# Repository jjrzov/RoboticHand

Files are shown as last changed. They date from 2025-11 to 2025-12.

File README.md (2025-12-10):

# ME 507 - Teleoperated Robot Hand
By: Sydney Alexander & Jorge Ramirez

This repository holds all the work done for our Fall 2025 ME 507 mechatronics 
class, Mechanical Control System Design. We chose to do a teleoperated
robot hand for our final project. The robot hand is controlled by a glove
that can be worn by the user. The user has control over each finger and a
palm bending motion on the robot hand.

The repository is split into 3 parts: 
* Mechanical Design Files (<https://github.com/jjrzov/RoboticHand/tree/main/CAD>)
* PCB Files
* Software Files    (<https://github.com/jjrzov/RoboticHand/tree/main/Code>)

More information can be found in the report:
<https://docs.google.com/document/d/1OJhpxcHGqPs-KphNlcnnhu6IluXgC120gNegF1xwxDM/edit?usp=sharing>

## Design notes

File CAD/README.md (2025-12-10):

This folder contains all of the CAD files necessary to construct the robotic hand.

Hand Assembly.SLDASM: Solidworks assembly containing the PCB, spacer, palm, mount, thumb, and one finger

Mount.SLDPRT: A Solidworks model of a mount for the hand to sit on

PCB Spacer.SLDPRT: A Solidworks model of a spacer to go between the palm and the PCB. Assembly contains 3

Palm.DXF: A DXF file of the palm that was used to design the PCB

Palm.SLDPRT: A Solidworks model of the palm, finger, and thumb

Passive Joint.SLDPRT: A Solidworks model of an attachment for the thumb joint (in Palm.SLDPRT)

RobotHandFINAL.step: A STEP file of the final PCB

Spool.SLDPRT: A Solidworks model of the spool. Assembly contains 5

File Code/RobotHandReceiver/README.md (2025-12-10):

# Robot Hand Receiver

This folder contians the platform.io project for the receiver in the project.
The receiver is tasked with receiving flex readings from the transmitter and
moving the motors to bend the finger(s) to match the user's movements.



There are 2 tasks for this project, the Receiver Task and the Controller Task. The Receiver Task is blocking waiting for the ESP-NOW callback to run meaning that data from the transmitter has arrived. The callback is made to be extermely fast and quick to ensure safe non critical behavior:

```
/**
 * @brief ESP-NOW receive callback.
 *
 * Copies the received packet into a FreeRTOS queue for processing
 * by ::ReceiverTask.
 *
 * @param mac          MAC address of sender.
 * @param incomingData Pointer to received data buffer.
 * @param len          Length of received data in bytes.
*/
void OnDataRecv(const uint8_t * mac, const uint8_t *incomingData, int len) {  
  Hand_Data data;
  memcpy(&data, incomingData, sizeof(data));
  xQueueSend(packet_queue, &data, 0);

  return;
}
```

Since the transmitter is unicasting specifically to the MAC address of the receiver ESP32, we do not need to worry about setting up the MAC address like we did in the receiver.

Once having received data the Receiver Task converts the raw flex readings into potentiometer-space targets:

```
float ratio = (flex_value - F_MIN) / (F_MAX - F_MIN);
float enc   = E_MIN + ratio * (E_MAX - E_MIN);
```
Each target is then sent to it's dedicated finger queue. Similar to the Transmitter Task, a Hand class is used to house all the queues.

The Controller Task implements a 2 state FSM:



Though before entering a state, the Controller reads from the encoders on each loop. There are rotary potentiometers attached to each motor that serve as encoder values. To read the current position of each motor, the potentiometers are connected to an 8 channel external ADC chip that communicates over I2C. We use the official Adafruit library for interfacing with this chip:

```
/**
 * @brief External ADC instance for rotary encoder (potentiometer) readings.
*/
Adafruit_ADS7830 ad7830;
```

In the Homing state, each funger motor is driver towards a known home position

```
Hand_Data home = {20, 20, 20, 20, 20, 20};
```

Once all the fingers are homed the system transition to Position Control state. During position control, the task performs non blocking reads of the latest target value from the finger queues:

```
if (xQueueReceive(glove.thumb_queue, &val, 0) == pdTRUE)
  targets.thumb_data = val;

```

For both Homing and Position Control, motor movement is calculated through a PID. Each finger/joint has its own PID that takes in the current potentiometer value and the target potentiometer value. There are 2 separate functions for running the PID in the Homing state versus the Position Control state. The Homing state only utilizes a P controller while the Position Control has a PID controller. 

```
void PositionControlFinger(uint32_t enc, uint32_t target, PID_t *pid, int pwm_channel, int phase_pin, float dt);

bool HomeFinger(uint32_t enc, uint32_t home_target, int pwm_channel, int phase_pin);
```

This distinction was made because when homing we only want to be around a certain threshold of potentiometer values to be home but we want more precise control when trying to match the user's motion.

The magnitude of the PID and P controller becomes the speed of the motor.

PID Controller:

```
float error = (float)target - (float)enc;
float u = PID_Step(pid, error, dt);  // signed

SetPhase(u, phase_pin); // Find direction to move in

float mag = fabsf(u);
int pwm = (int)mag;
```

P Controller:
```
float u = HOMING_KP * (float)err;
SetPhase(u, phase_pin);

float mag_u = fabsf(u);
int pwm = (int)mag_u; 
```

while the direction comes from the sign of the output.

```
/**
 * @brief Set motor direction based on signed control effort.
 *
 * Uses the sign of the control signal to determine the motor
 * rotation direction via the phase pin.
 *
 * @param u               Signed control output.
 * @param motor_phase_pin GPIO pin controlling motor direction.
 */
void SetPhase(float u, uint32_t motor_phase_pin) {
  digitalWrite(motor_phase_pin,(u >= 0.0f) ? HIGH : LOW);
}
```

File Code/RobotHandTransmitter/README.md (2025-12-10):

# Robot Hand Transmitter

This folder holds the platform.io project for the transmitter. The main task of
this project is to read the bend of the glove and transmit the data to the 
receiver.

In order to mimic the user's hand motions while wearing the glove, we used flex
sensors that act like potentiometers. Depending on how much the user is bending
the flex sensor, the resistance will increase or decrease. By creating a simple
voltage divider circuit with the flex sensor and a 100 ohm resistor, we can read
how the voltage is changing through ADC channels on our ESP-32.



Delving into the software, we can see the basic task architecure above. There are only 2 tasks for this project with the read sensors task running every 10ms and then sending that data over to the transmit task to then be sent to the receiver. 

Each finger has its own queue when communicating between tasks, but to make the code simpler a Hand class was created. This Hand class holds all the queues and is used as a way to access each queue from the tasks.

In the read sensors task, the voltage is read from each flex sensor and published to a queue. The transmit task is constantly reading from each queue until it is empty. An average is then taken while making sure to avoid dividng by zero. 

```
  // Read from queue until empty and take average
  while(xQueueReceive(queue, &reading, 0) == pdTRUE) {
    sum += reading;
    count++;
  }

  if (count > 0) {
    return (sum / count);
  } else {
    return 0; // Don't want to divide by zero if nothing in queue
  }
```

Setup for ESP-NOW is all done in the setup function before the scheduler begins. To avoid broadcasting to any ESP-32s nearby, we broadcast specifically to the MAC address of the device we want

```
  // Register peer
  memcpy(peerInfo.peer_addr, BROADCAST_ADDRESS, 6);
  peerInfo.channel = 0;  
  peerInfo.encrypt = false;

  // Add peer        
  if (esp_now_add_peer(&peerInfo) != ESP_OK){
    Serial.println("Failed to add peer");
    return false;
  }
```

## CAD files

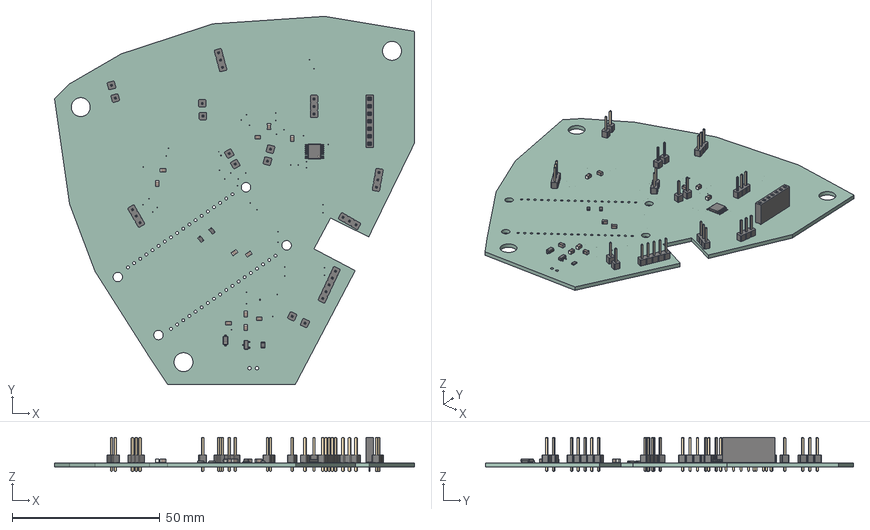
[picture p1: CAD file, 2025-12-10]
CAD/RobotHandFINAL.step
121.9 x 124.7 x 11.6 mm
D_SOD-123
R_0805_2012Metric x 3
PinHeader_1x01_P2.54mm_Vertical x 10
C_0805_2012Metric x 11
PinHeader_1x03_P2.54mm_Vertical x 5
PinSocket_1x07_P2.54mm_Vertical
PinHeader_1x05_P2.54mm_Vertical
TSSOP-16_4.4x5mm_P0.65mm
SOT-23-3
RobotHandFINAL_PCB

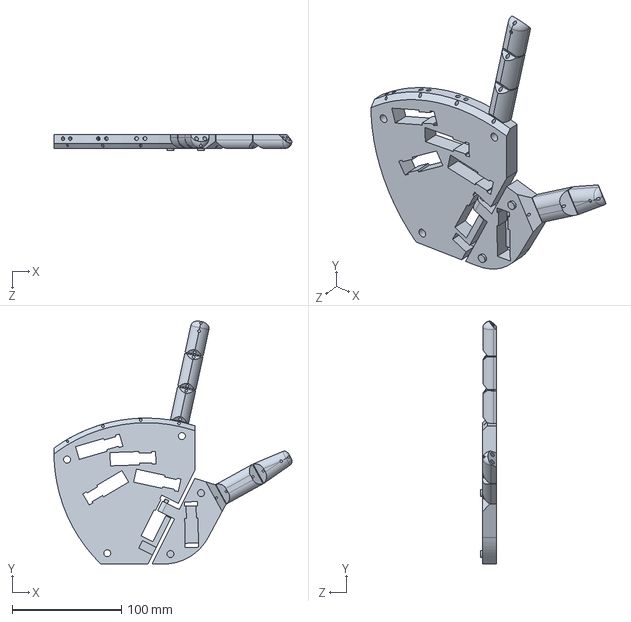
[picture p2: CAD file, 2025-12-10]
CAD/Palm.SLDPRT
217.5 x 222.1 x 14.7 mm

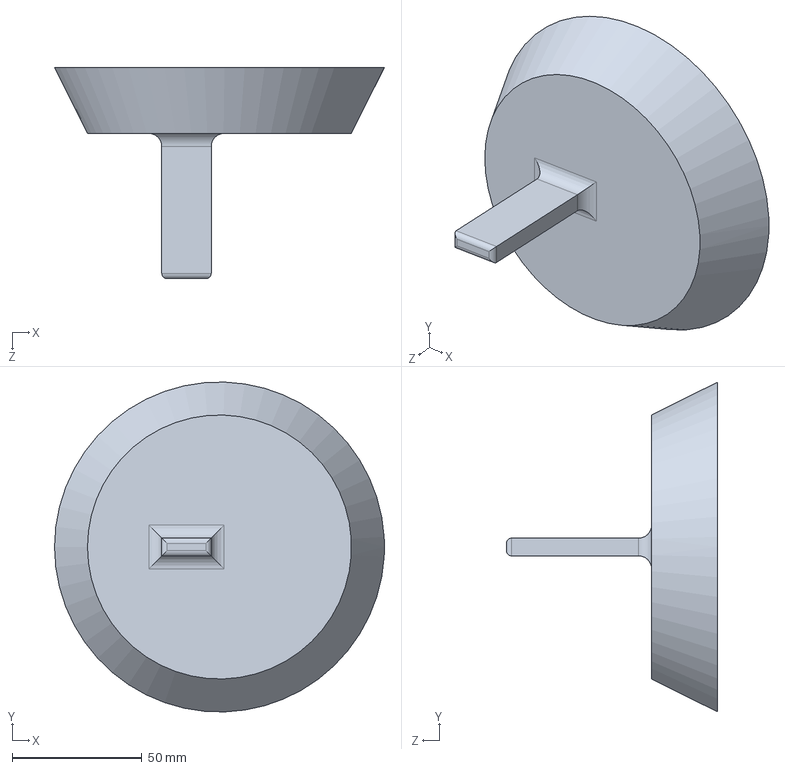
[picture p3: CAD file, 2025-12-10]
CAD/Mount.SLDPRT
127.0 x 126.9 x 81.3 mm

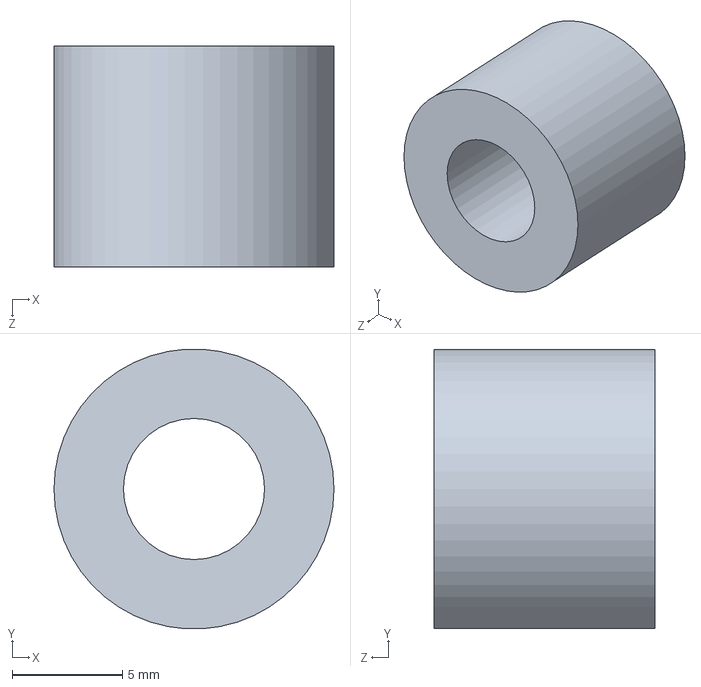
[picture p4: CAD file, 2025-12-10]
CAD/PCB Spacer.SLDPRT
12.7 x 12.7 x 10.0 mm

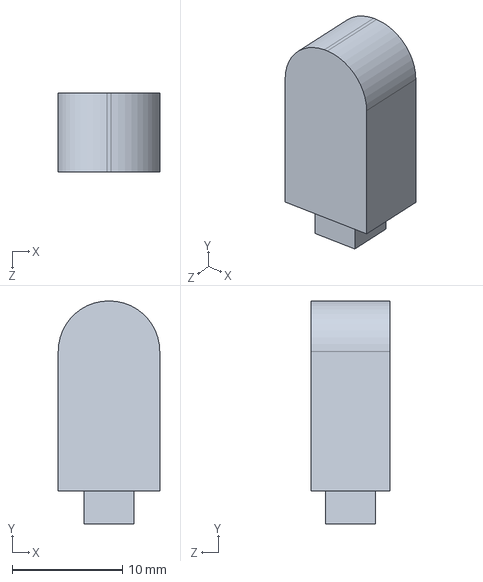
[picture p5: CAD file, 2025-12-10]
CAD/Passive Joint.SLDPRT
9.23 x 20.3 x 7.14 mm

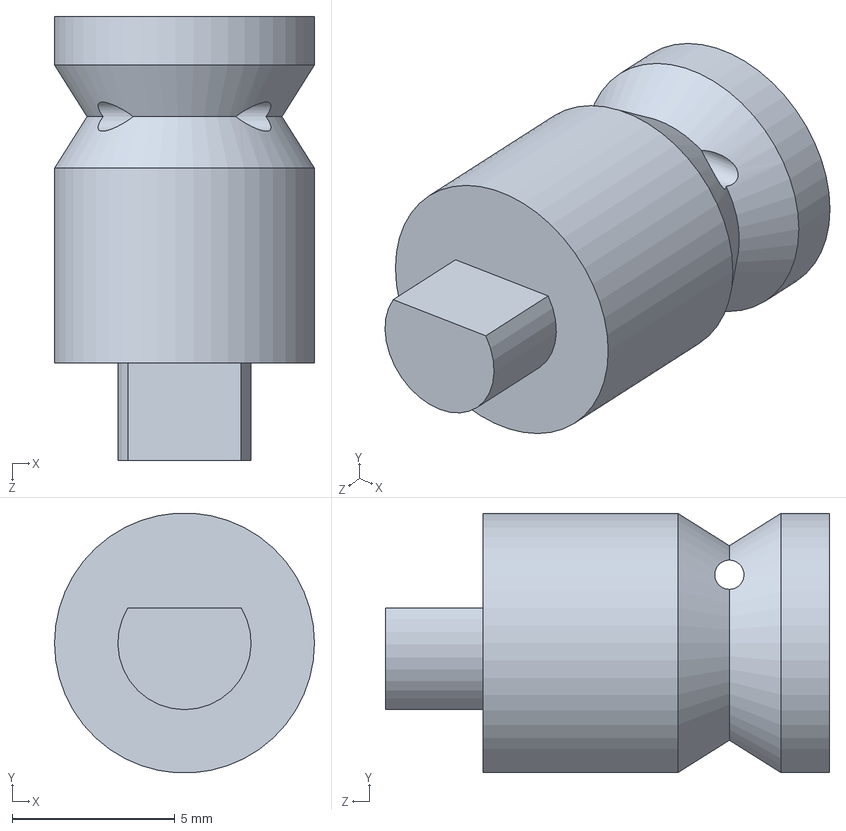
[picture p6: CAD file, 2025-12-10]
CAD/Spool.SLDPRT
8.00 x 7.98 x 13.7 mm

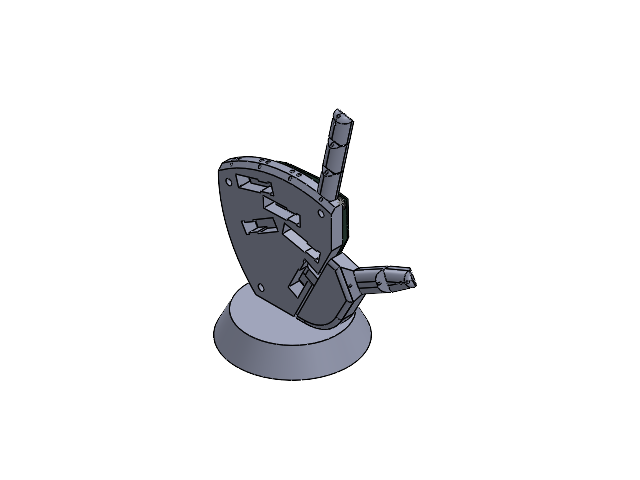
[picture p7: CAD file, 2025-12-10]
CAD/Hand Assembly.SLDASM
Palm
D_SOD-123.step
R_0805_2012Metric.step x 3
PinHeader_1x01_P2.54mm_Vertical.step x 10
C_0805_2012Metric.step x 11
PinHeader_1x03_P2.54mm_Vertical.step x 5
PinSocket_1x07_P2.54mm_Vertical.step
PinHeader_1x05_P2.54mm_Vertical.step
TSSOP-16_4.4x5mm_P0.65mm.step
SOT-23-3.step
RobotHandFINAL_PCB.step
PCB Spacer
Mount

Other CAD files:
CAD/Palm.DXF

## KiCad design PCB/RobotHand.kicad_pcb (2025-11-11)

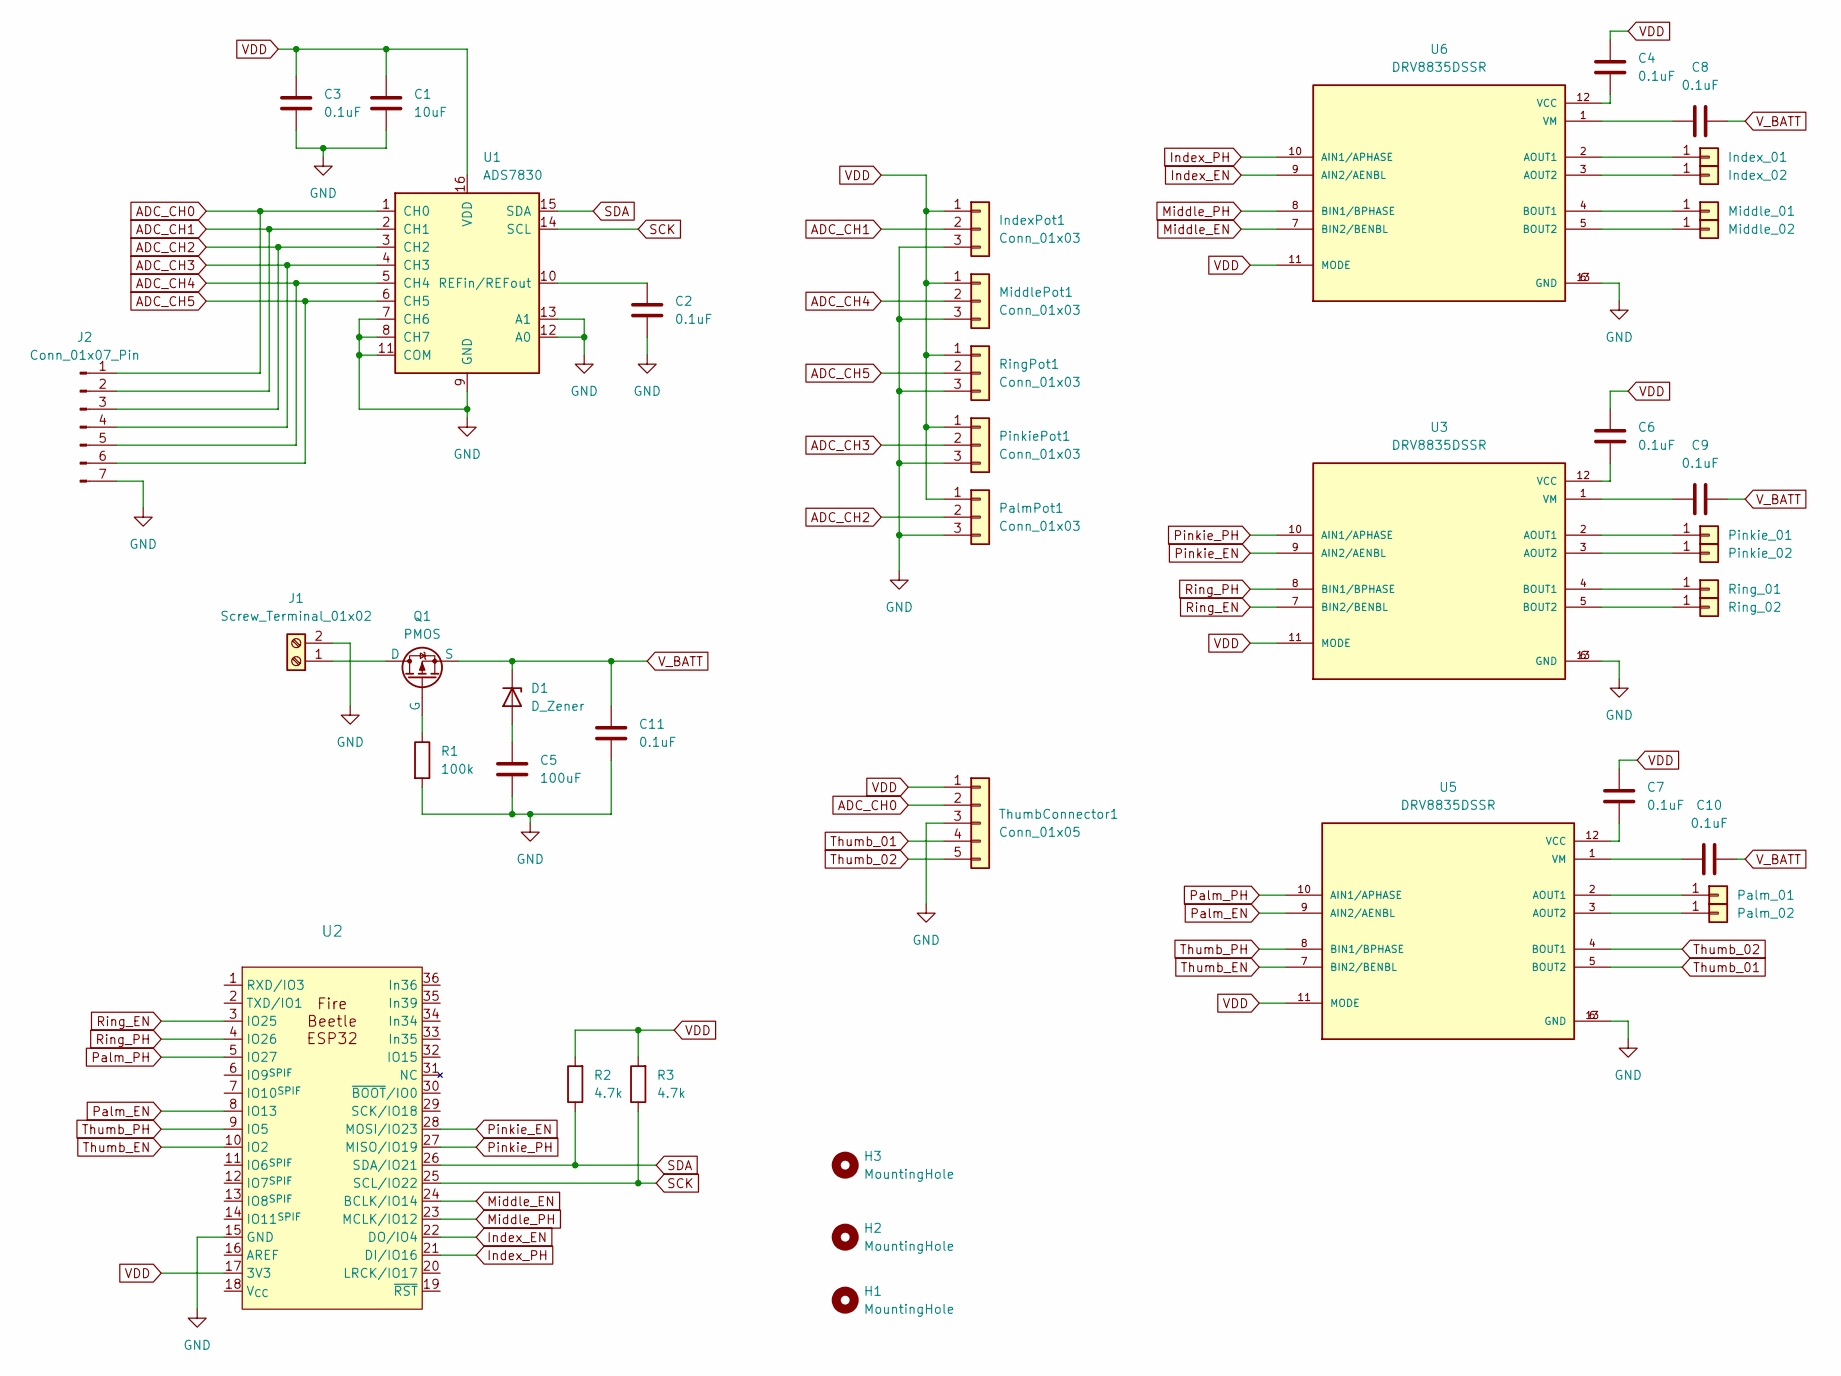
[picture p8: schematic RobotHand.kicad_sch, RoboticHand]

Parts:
C1: 10uF; C_0805_2012Metric_Pad1.18x1.45mm_HandSolder
C2, C3, C4, C6, C7, C8, C9, C10, C11: 0.1uF; C_0805_2012Metric_Pad1.18x1.45mm_HandSolder
C5: 100uF; C_0805_2012Metric_Pad1.18x1.45mm_HandSolder
D1: D_Zener; D_SOD-123
H1, H2, H3: MountingHole; MountingHole_6.4mm_M6
IndexPot1: Conn_01x03; PinHeader_1x03_P2.54mm_Vertical
Index_01, Index_02: Conn_01x01; PinHeader_1x01_P2.54mm_Vertical
J1: Screw_Terminal_01x02; TerminalBlock_Xinya_XY308-2.54-2P_1x02_P2.54mm_Horizontal
J2: Conn_01x07_Pin; PinSocket_1x07_P2.54mm_Vertical
MiddlePot1: Conn_01x03; PinHeader_1x03_P2.54mm_Vertical
Middle_01, Middle_02: Conn_01x01; PinHeader_1x01_P2.54mm_Vertical
PalmPot1: Conn_01x03; PinHeader_1x03_P2.54mm_Vertical
Palm_01, Palm_02: Conn_01x01; PinHeader_1x01_P2.54mm_Vertical
PinkiePot1: Conn_01x03; PinHeader_1x03_P2.54mm_Vertical
Pinkie_01, Pinkie_02: Conn_01x01; PinHeader_1x01_P2.54mm_Vertical
Q1: PMOS; SOT-23-3
R1: 100k; R_0805_2012Metric
R2, R3: 4.7k; R_0805_2012Metric
RingPot1: Conn_01x03; PinHeader_1x03_P2.54mm_Vertical
Ring_01, Ring_02: Conn_01x01; PinHeader_1x01_P2.54mm_Vertical
ThumbConnector1: Conn_01x05; PinHeader_1x05_P2.54mm_Vertical
U1: ADS7830; TSSOP-16_4.4x5mm_P0.65mm
U2: FireBeetle-ESP32
U3, U5, U6: DRV8835DSSR; WSON-12-1EP_3x2mm_P0.5mm_EP1x2.65; PARTREV H

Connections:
ADC_CH0: J2.1, ThumbConnector1.2, U1.1 (CH0)
ADC_CH1: IndexPot1.2, J2.2, U1.2 (CH1)
ADC_CH2: J2.3, PalmPot1.2, U1.3 (CH2)
ADC_CH3: J2.4, PinkiePot1.2, U1.4 (CH3)
ADC_CH4: J2.5, MiddlePot1.2, U1.5 (CH4)
ADC_CH5: J2.6, RingPot1.2, U1.6 (CH5)
GND: C1.1, C2.2, C3.2, C5.2, C11.2, IndexPot1.3, J1.2, J2.7, MiddlePot1.3, PalmPot1.3, PinkiePot1.3, R1.2, RingPot1.3, ThumbConnector1.3, U1.7 (CH6), U1.8 (CH7), U1.9 (GND), U1.11 (COM), U1.12 (A0), U1.13 (A1), U2.15 (GND), U3.6 (GND), U3.13 (GND), U5.6 (GND), U5.13 (GND), U6.6 (GND), U6.13 (GND)
Index_EN: U2.22 (DO/IO4), U6.9 (AIN2/AENBL)
Index_PH: U2.21 (DI/IO16), U6.10 (AIN1/APHASE)
Middle_EN: U2.24 (BCLK/IO14), U6.7 (BIN2/BENBL)
Middle_PH: U2.23 (MCLK/IO12), U6.8 (BIN1/BPHASE)
unnamed: C5.1, D1.2 (A)
unnamed: Index_01.1, U6.2 (AOUT1)
unnamed: Index_02.1, U6.3 (AOUT2)
unnamed: J1.1, Q1.1 (D)
unnamed: Middle_01.1, U6.4 (BOUT1)
unnamed: Middle_02.1, U6.5 (BOUT2)
unnamed: Palm_01.1, U5.2 (AOUT1)
unnamed: Palm_02.1, U5.3 (AOUT2)
unnamed: Pinkie_01.1, U3.2 (AOUT1)
unnamed: Pinkie_02.1, U3.3 (AOUT2)
unnamed: Q1.2 (G), R1.1
unnamed: Ring_01.1, U3.4 (BOUT1)
unnamed: Ring_02.1, U3.5 (BOUT2)
unnamed: C2.1, U1.10 (REFin/REFout)
unnamed: C6.1, U3.12 (VCC)
unnamed: C9.1, U3.1 (VM)
unnamed: C7.1, U5.12 (VCC)
unnamed: C10.2, U5.1 (VM)
unnamed: C4.1, U6.12 (VCC)
unnamed: C8.1, U6.1 (VM)
Palm_EN: U2.8 (IO13), U5.9 (AIN2/AENBL)
Palm_PH: U2.5 (IO27), U5.10 (AIN1/APHASE)
Pinkie_EN: U2.28 (MOSI/IO23), U3.9 (AIN2/AENBL)
Pinkie_PH: U2.27 (MISO/IO19), U3.10 (AIN1/APHASE)
Ring_EN: U2.3 (IO25), U3.7 (BIN2/BENBL)
Ring_PH: U2.4 (IO26), U3.8 (BIN1/BPHASE)
SCK: R3.1, U1.14 (SCL), U2.25 (SCL/IO22)
SDA: R2.1, U1.15 (SDA), U2.26 (SDA/IO21)
Thumb_01: ThumbConnector1.4, U5.5 (BOUT2)
Thumb_02: ThumbConnector1.5, U5.4 (BOUT1)
Thumb_EN: U2.10 (IO2), U5.7 (BIN2/BENBL)
Thumb_PH: U2.9 (IO5), U5.8 (BIN1/BPHASE)
VDD: C1.2, C3.1, C4.2, C6.2, C7.2, IndexPot1.1, MiddlePot1.1, PalmPot1.1, PinkiePot1.1, R2.2, R3.2, RingPot1.1, ThumbConnector1.1, U1.16 (VDD), U2.17 (3V3), U3.11 (MODE), U5.11 (MODE), U6.11 (MODE)
V_BATT: C8.2, C9.2, C10.1, C11.1, D1.1 (K), Q1.3 (S)

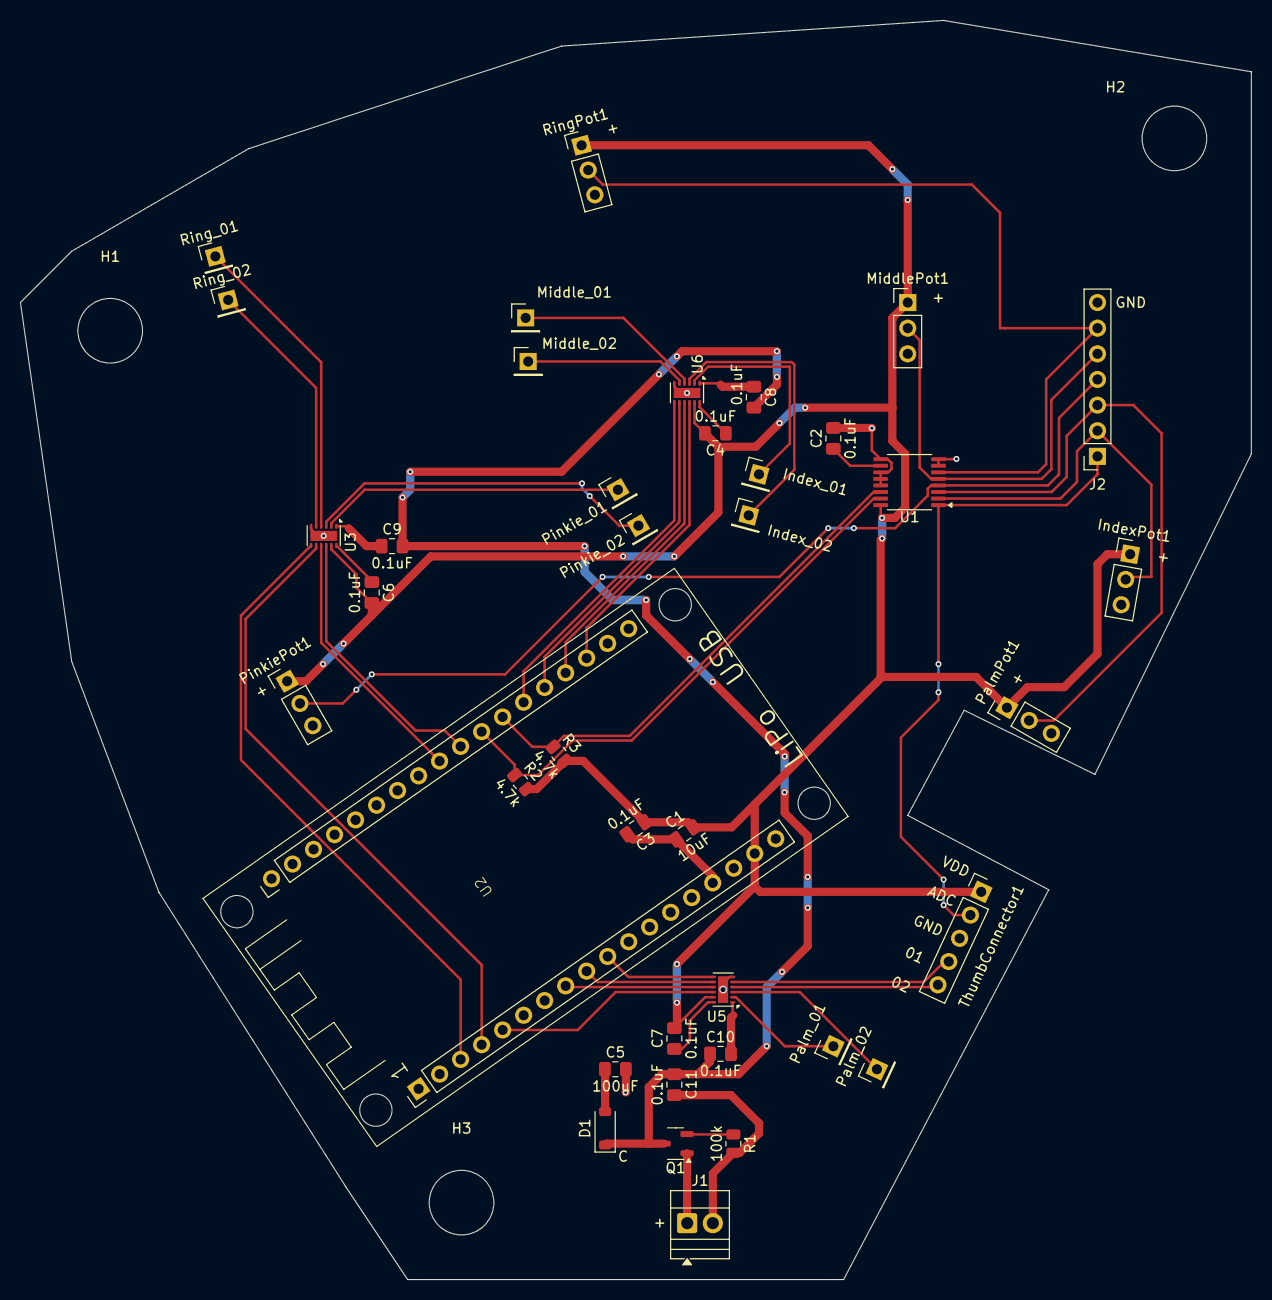
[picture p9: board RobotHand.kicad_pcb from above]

Board: 2 copper layers, 121.9 x 124.7 mm, 42 parts (0 on the bottom side), 45 nets.

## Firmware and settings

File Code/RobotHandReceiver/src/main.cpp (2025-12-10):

/**
 * @file main.cpp
 * @brief ESP-NOW robotic hand receiver and PID motor controller.
 *
 * This application:
 *  - Receives flex sensor data via ESP-NOW
 *  - Converts flex readings to encoder targets
 *  - Performs homing and position control using PID
 *  - Drives DC motors using PWM + phase control
 *
 * FreeRTOS tasks are used for communication and control.
 */

#include "Constants.h"
#include "pid.h"

/** @name PID controllers for each finger and palm
 *  @{
 */
PID_t pid_thumb;
PID_t pid_index;
PID_t pid_middle;
PID_t pid_ring;
PID_t pid_pinkie;
PID_t pid_palm;
/** @} */


/**
 * @brief Queue container for desired encoder targets for each finger.
 */
Hand_Queues glove = Hand_Queues();

/**
 * @brief Queue used to receive ESP-NOW packets from the glove transmitter.
 */
QueueHandle_t packet_queue = xQueueCreate(1, sizeof(Hand_Data));


/**
 * @brief External ADC instance for rotary encoder (potentiometer) readings.
 */
Adafruit_ADS7830 ad7830;

/**
 * @brief ESP-NOW peer information structure.
 */
esp_now_peer_info_t peerInfo;


/**
 * @brief Convert flex sensor reading to encoder target value.
 *
 * Performs clamping and linear interpolation between calibrated
 * flex sensor limits and encoder limits.
 *
 * @param flex_value Raw flex sensor reading.
 * @return Corresponding encoder target value.
 */
uint32_t FlexToEncoder(uint32_t flex_value) { 
  // Clamp input
  if (flex_value <= F_MIN) return (uint32_t)E_MIN;
  if (flex_value >= F_MAX) return (uint32_t)E_MAX;

  // Linear interpolation
  float ratio = (flex_value - F_MIN) / (F_MAX - F_MIN);
  float enc = E_MIN + ratio * (E_MAX - E_MIN);

  return (uint32_t)enc;
}

/**
 * @brief FreeRTOS task that processes received ESP-NOW packets.
 *
 * This task:
 *  - Waits for incoming Hand_Data packets
 *  - Converts flex values to encoder targets
 *  - Dispatches targets to individual finger queues
 *
 * @param p_params Task parameters (unused).
 */
void ReceiverTask(void *p_params) {
  Hand_Data recv_data, enc_data;
  
  while(1) {
    if (xQueueReceive(packet_queue, &recv_data, portMAX_DELAY) == pdTRUE) {
      // Convert from flex value to encoder value
      enc_data.thumb_data = FlexToEncoder(recv_data.thumb_data);
      enc_data.index_data = FlexToEncoder(recv_data.index_data);
      enc_data.middle_data = FlexToEncoder(recv_data.middle_data);
      enc_data.ring_data = FlexToEncoder(recv_data.ring_data);
      enc_data.pinkie_data = FlexToEncoder(recv_data.pinkie_data);
      enc_data.palm_data = FlexToEncoder(recv_data.palm_data);

      // Send data to other tasks with queue
      xQueueSend(glove.thumb_queue, &enc_data.thumb_data, 0);
      xQueueSend(glove.index_queue, &enc_data.index_data, 0);
      xQueueSend(glove.middle_queue, &enc_data.middle_data, 0);
      xQueueSend(glove.ring_queue, &enc_data.ring_data, 0);
      xQueueSend(glove.pinkie_queue, &enc_data.pinkie_data, 0);
      xQueueSend(glove.palm_queue, &enc_data.palm_data, 0);
    }
  }
}

/**
 * @brief ESP-NOW receive callback.
 *
 * Copies the received packet into a FreeRTOS queue for processing
 * by ::ReceiverTask.
 *
 * @param mac          MAC address of sender.
 * @param incomingData Pointer to received data buffer.
 * @param len          Length of received data in bytes.
 */
void OnDataRecv(const uint8_t * mac, const uint8_t *incomingData, int len) {  
  Hand_Data data;
  memcpy(&data, incomingData, sizeof(data));
  xQueueSend(packet_queue, &data, 0);

  return;
}


/**
 * @brief Initialize ESP-NOW communication subsystem.
 *
 * Sets WiFi to station mode, initializes ESP-NOW,
 * and registers the receive callback.
 *
 * @return true on success, false on failure.
 */
bool InitComms() {
  // Set device as a Wi-Fi Station
  WiFi.mode(WIFI_STA);

  // Init ESP-NOW
  if (esp_now_init() != ESP_OK) {
    Serial.println("Error initializing ESP-NOW");
    return false;
  }

  // Once ESPNow is successfully Init, we will register for recv CB to get recv packet info
  esp_now_register_recv_cb(OnDataRecv);

  return true;
}

/**
 * @brief Initialize the external ADS7830 ADC.
 *
 * @return true if ADC initialization succeeds, false otherwise.
 */
bool InitADC() {
  // Initialize external ADC
  if (!ad7830.begin()) {
    Serial.println("Failed to initialize ADS7830");
    return false;
  }
  return true;
}

/**
 * @brief Initialize PWM channels and GPIOs for all motors.
 *
 * Configures PWM frequency, resolution, output pins,
 * and phase direction pins for each motor.
 */
void InitMotors() {
  // Initialize pins to control motors

  // Thumb
  ledcSetup(THUMB_PWM_CHANNEL, MOTOR_PWM_FREQ, MOTOR_PWM_RESOLUTION);
  ledcAttachPin(THUMB_PWM_PIN, THUMB_PWM_CHANNEL);
  pinMode(THUMB_PH_PIN, OUTPUT);

  // Index
  ledcSetup(INDEX_PWM_CHANNEL, MOTOR_PWM_FREQ, MOTOR_PWM_RESOLUTION);
  ledcAttachPin(INDEX_PWM_PIN, INDEX_PWM_CHANNEL);
  pinMode(INDEX_PH_PIN, OUTPUT);

  // Middle
  ledcSetup(MIDDLE_PWM_CHANNEL, MOTOR_PWM_FREQ, MOTOR_PWM_RESOLUTION);
  ledcAttachPin(MIDDLE_PWM_PIN, MIDDLE_PWM_CHANNEL);
  pinMode(MIDDLE_PH_PIN, OUTPUT);

  // Ring
  ledcSetup(RING_PWM_CHANNEL, MOTOR_PWM_FREQ, MOTOR_PWM_RESOLUTION);
  ledcAttachPin(RING_PWM_PIN, RING_PWM_CHANNEL);
  pinMode(RING_PH_PIN, OUTPUT);

  // Pinkie
  ledcSetup(PINKIE_PWM_CHANNEL, MOTOR_PWM_FREQ, MOTOR_PWM_RESOLUTION);
  ledcAttachPin(PINKIE_PWM_PIN, PINKIE_PWM_CHANNEL);
  pinMode(PINKIE_PH_PIN, OUTPUT);

  // Palm
  ledcSetup(PALM_PWM_CHANNEL, MOTOR_PWM_FREQ, MOTOR_PWM_RESOLUTION);
  ledcAttachPin(PALM_PWM_PIN, PALM_PWM_CHANNEL);
  pinMode(PALM_PH_PIN, OUTPUT);
  return;
}

/**
 * @brief Read a rotary encoder value via the external ADC.
 *
 * @param ext_adc_num External ADC channel number.
 * @return Raw ADC reading corresponding to encoder position.
 */
uint32_t ReadEncoder(uint8_t ext_adc_num) {
  // Read encoder value from rotary potentiometer
  return ad7830.readADCsingle(ext_adc_num);
}

/**
 * @brief Stop all motors immediately.
 *
 * Sets all PWM duty cycles to zero.
 */
void StopAllMotors() {
  // Turn off all motors by setting pwm to zero
  ledcWrite(THUMB_PWM_CHANNEL, 0);
  ledcWrite(INDEX_PWM_CHANNEL, 0);
  ledcWrite(MIDDLE_PWM_CHANNEL, 0);
  ledcWrite(RING_PWM_CHANNEL, 0);
  ledcWrite(PINKIE_PWM_CHANNEL, 0);
  ledcWrite(PALM_PWM_CHANNEL, 0);
  return;
}

/**
 * @brief Main control FreeRTOS task implementing the hand state machine.
 *
 * States:
 *  - HOMING_STATE: Drive all fingers to known home positions
 *  - POSITION_CONTROL_STATE: Run PID control using received targets
 *
 * @param p_params Task parameters (unused).
 */
void ControllerTask(void *p_params) {
  HandState state = HOMING_STATE;

  // home encoder counts
  Hand_Data home = {20, 20, 20, 20, 20, 20};

  // current target positions (for POSITION_CONTROL)
  Hand_Data targets = home;  // start at home

  InitPIDs();
  ResetAllPIDs();

  const float dt = 0.02f; // 20 ms in seconds

  while(1) {
    Serial.print("State: ");
    Serial.println(state);
    // Read actual encoder values 
    uint32_t enc_thumb = ReadEncoder(EXT_ADC_THUMB);
    uint32_t enc_index = ReadEncoder(EXT_ADC_INDEX);
    uint32_t enc_middle = ReadEncoder(EXT_ADC_MIDDLE);
    uint32_t enc_ring = ReadEncoder(EXT_ADC_RING);
    uint32_t enc_pinkie = ReadEncoder(EXT_ADC_PINKIE);
    uint32_t enc_palm = ReadEncoder(EXT_ADC_PALM);

    switch (state) {
      case HOMING_STATE: {
        bool thumb_ok  = HomeFinger(enc_thumb,  home.thumb_data,
                                    THUMB_PWM_CHANNEL,  THUMB_PH_PIN);

        bool index_ok  = HomeFinger(enc_index,  home.index_data,
                                    INDEX_PWM_CHANNEL,  INDEX_PH_PIN);

        bool middle_ok  = HomeFinger(enc_middle,  home.middle_data,
                                    MIDDLE_PWM_CHANNEL,  MIDDLE_PH_PIN);

        bool ring_ok  = HomeFinger(enc_ring,  home.ring_data,
                                    RING_PWM_CHANNEL,  RING_PH_PIN);

        bool pinkie_ok  = HomeFinger(enc_pinkie,  home.pinkie_data,
                                    PINKIE_PWM_CHANNEL,  PINKIE_PH_PIN);

        bool palm_ok  = HomeFinger(enc_palm,  home.palm_data,
                                    PALM_PWM_CHANNEL,  PALM_PH_PIN);

        bool all_homed = thumb_ok && index_ok && middle_ok && ring_ok 
                              && pinkie_ok && palm_ok;

        if (all_homed) {
          StopAllMotors();
          state = POSITION_CONTROL_STATE;
        }
        break;
      }

      case POSITION_CONTROL_STATE: {
        // Get latest desired targets from ESP-NOW queues (non-blocking)
        uint32_t val;

        if (xQueueReceive(glove.thumb_queue,  &val, 0) == pdTRUE) {
          targets.thumb_data = val;
        }

        if (xQueueReceive(glove.index_queue,  &val, 0) == pdTRUE) {
          targets.index_data = val;
        }

        if (xQueueReceive(glove.middle_queue,  &val, 0) == pdTRUE) {
          targets.middle_data = val;
        }

        if (xQueueReceive(glove.ring_queue,  &val, 0) == pdTRUE) {
          targets.ring_data = val;
        }

        if (xQueueReceive(glove.pinkie_queue,  &val, 0) == pdTRUE) {
          targets.pinkie_data = val;
        }

        if (xQueueReceive(glove.palm_queue,  &val, 0) == pdTRUE) {
          targets.palm_data = val;
        }
        
        // Run PID for each finger
        PositionControlFinger(enc_thumb,  targets.thumb_data,
                              &pid_thumb,  THUMB_PWM_CHANNEL,  THUMB_PH_PIN,  dt);

        PositionControlFinger(enc_index,  targets.index_data,
                              &pid_index,  INDEX_PWM_CHANNEL,  INDEX_PH_PIN,  dt);

        PositionControlFinger(enc_middle,  targets.middle_data,
                              &pid_middle,  MIDDLE_PWM_CHANNEL,  MIDDLE_PH_PIN,  dt);

        PositionControlFinger(enc_ring,  targets.ring_data,
                              &pid_ring,    RING_PWM_CHANNEL,  RING_PH_PIN,  dt);

        PositionControlFinger(enc_pinkie,  targets.pinkie_data,
                              &pid_pinkie,  PINKIE_PWM_CHANNEL,  PINKIE_PH_PIN,  dt);

        PositionControlFinger(enc_palm,  targets.palm_data,
                              &pid_palm,  PALM_PWM_CHANNEL,  PALM_PH_PIN,  dt);

        break;
      }
      
      default:
        StopAllMotors();
        break;
    }

    vTaskDelay(20 / portTICK_PERIOD_MS);  // 20ms period
  }
}

/**
 * @brief Arduino setup function.
 *
 * Initializes communication, ADC, motors, and creates FreeRTOS tasks.
 */
void setup() {
  Serial.begin(115200);
  delay(2000);
  BaseType_t retVal;

  InitComms();
  InitADC();
  InitMotors();

  retVal = xTaskCreate(ControllerTask, "Controller Task", 2048, NULL, 1, NULL);
  if (retVal != pdPASS) {
    Serial.println("Failed to create Bootup Task\n");
  }
  
  retVal = xTaskCreate(ReceiverTask, "Receiver Task", 1024, NULL, 2, NULL);
  if (retVal != pdPASS) {
    Serial.println("Failed to create Receiver Task\n");
  }

}

/**
 * @brief Arduino main loop (unused).
 */
void loop() {
  vTaskDelay(1000000);
}

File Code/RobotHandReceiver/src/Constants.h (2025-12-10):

/**
 * @file Constants.h
 * @brief Hardware configuration, calibration values, and shared data types.
 *
 * This file centralizes all system-wide constants for:
 *  - External ADC channel mappings
 *  - Motor control parameters
 *  - Homing thresholds and gains
 *  - Flex sensor and encoder calibration
 *  - Shared data structures and state enums
 *
 * All values here are platform- and hardware-specific.
 */

#ifndef CONSTANTS_H
#define CONSTANTS_H

#include <Arduino.h>
#include <Adafruit_ADS7830.h>
#include <esp_now.h>
#include <WiFi.h>

/** @name External ADC channel assignments
 *  @brief ADS7830 channel numbers for each finger encoder.
 *  @{
 */
const uint8_t EXT_ADC_THUMB = 0;
const uint8_t EXT_ADC_INDEX = 1;
const uint8_t EXT_ADC_MIDDLE = 4;
const uint8_t EXT_ADC_RING = 5;
const uint8_t EXT_ADC_PINKIE = 3;
const uint8_t EXT_ADC_PALM = 2;
/** @} */

/** @name Homing control parameters
 *  @brief Gains and thresholds used during finger homing.
 *  @{
 */
const float HOMING_KP = 0.5f;
const uint32_t HOMING_PWM_MIN = 150;
const uint32_t HOMING_PWM_MAX = 800;
const uint32_t HOMING_THRESHOLD = 20;
/** @} */

/** @name Motor PWM configuration
 *  @brief Global PWM parameters shared across all motors.
 *  @{
 */
const int MOTOR_PWM_FREQ = 15000;     // 15kHz PWM Signal
const int MOTOR_PWM_RESOLUTION = 10;  // 10 bit PWM Resolution
/** @} */


/** @name Motor pin and channel mappings
 *  @brief PWM channels, output pins, and phase pins for each motor.
 *  @{
 */
const int THUMB_PWM_CHANNEL = 0;      // LED PWM Channel 0
const int THUMB_PWM_PIN = 2;  // GPIO 5
const int THUMB_PH_PIN = 5;   // GPIO 2

const int INDEX_PWM_CHANNEL = 1;      // LED PWM Channel 1
const int INDEX_PWM_PIN = 4;  // GPIO 4
const int INDEX_PH_PIN = 16;   // GPIO 16

const int MIDDLE_PWM_CHANNEL = 2;      // LED PWM Channel 2
const int MIDDLE_PWM_PIN = 14;  // GPIO 14
const int MIDDLE_PH_PIN = 12;   // GPIO 12

const int RING_PWM_CHANNEL = 3;      // LED PWM Channel 3
const int RING_PWM_PIN = 25;  // GPIO 25
const int RING_PH_PIN = 26;   // GPIO 26

const int PINKIE_PWM_CHANNEL = 4;      // LED PWM Channel 4
const int PINKIE_PWM_PIN = 23;  // GPIO 23
const int PINKIE_PH_PIN = 19;   // GPIO 19

const int PALM_PWM_CHANNEL = 5;      // LED PWM Channel 5
const int PALM_PWM_PIN = 13;  // GPIO 13
const int PALM_PH_PIN = 27;   // GPIO 27
/** @} */


/** @name Flex sensor calibration
 *  @brief Expected flex sensor range corresponding to open/closed hand.
 *  @{
 */
const float F_MIN = 142.0f;   // flex at fully open
const float F_MAX = 1100.0f;   // flex at fully closed
/** @} */

/** @name Encoder calibration
 *  @brief Encoder range corresponding to open/closed hand.
 *  @{
 */
const float E_MIN = 15.0f;     // encoder at fully open
const float E_MAX = 240.0f;   // encoder at fully closed
/** @} */

/**
 * @brief Data packet containing per-finger values.
 *
 * Used for:
 *  - ESP-NOW communication
 *  - Queue-based inter-task data passing
 */
struct Hand_Data {
  uint16_t thumb_data;
  uint16_t index_data;
  uint16_t middle_data;
  uint16_t ring_data;
  uint16_t pinkie_data;
  uint16_t palm_data;
};

/**
 * @brief Container for per-finger FreeRTOS queues.
 *
 * Each queue holds the most recent target encoder value
 * for its corresponding motor.
 */
class Hand_Queues {
    public:
        QueueHandle_t thumb_queue;
        QueueHandle_t index_queue;
        QueueHandle_t middle_queue;
        QueueHandle_t ring_queue;
        QueueHandle_t pinkie_queue;
        QueueHandle_t palm_queue;

        /**
        * @brief Construct a new Hand_Queues object.
        *
        * Initializes all queues with a depth of one element.
        */
        Hand_Queues() {
          thumb_queue = xQueueCreate(1, sizeof(uint16_t));
          index_queue = xQueueCreate(1, sizeof(uint16_t));
          middle_queue = xQueueCreate(1, sizeof(uint16_t));
          ring_queue = xQueueCreate(1, sizeof(uint16_t));
          pinkie_queue = xQueueCreate(1, sizeof(uint16_t));
          palm_queue = xQueueCreate(1, sizeof(uint16_t));
        }
};


/**
 * @brief State machine states for hand controller.
 */
typedef enum {
    HOMING_STATE,
    POSITION_CONTROL_STATE
} HandState;

#endif

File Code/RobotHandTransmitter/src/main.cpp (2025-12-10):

/**
 * @file main.cpp
 * @brief ESP-NOW glove transmitter using FreeRTOS tasks to read flex sensors and send averaged values.
 */

#include "main.h"

/** @brief ESP-NOW peer configuration information. */
esp_now_peer_info_t peerInfo;

/** @brief Global Hand instance representing the glove and its sensor queues. */
Hand glove = Hand();

/**
 * @brief FreeRTOS task that continuously reads flex sensors and pushes values into per-finger queues.
 *
 * The task:
 *  - Configures ADC resolution and attenuation.
 *  - Periodically reads each sensor using ::SendToQueue.
 *  - Logs an error over Serial if queue send fails.
 *
 * @param p_params Pointer to task parameters (unused).
 */
void ReadSensorsTask(void *p_params) {
  // Set ADC settings
  analogReadResolution(ADC_RESOLUTION);
  analogSetAttenuation(ADC_ATTENUATION);

  BaseType_t retVal;

  while(1) {
    // Read latest sensor data and add to queue for each finger
    retVal = SendToQueue(THUMB_PIN, glove.thumb_queue);
    if (retVal != pdPASS) {
      Serial.println("Failed to add to thumb queue\n");
    }

    retVal = SendToQueue(INDEX_PIN, glove.index_queue);
    if (retVal != pdPASS) {
      Serial.println("Failed to add to index queue\n");
    }

    retVal = SendToQueue(MIDDLE_PIN, glove.middle_queue);
    if (retVal != pdPASS) {
      Serial.println("Failed to add to middle queue\n");
    }

    retVal = SendToQueue(RING_PIN, glove.ring_queue);
    if (retVal != pdPASS) {
      Serial.println("Failed to add to ring queue\n");
    }

    retVal = SendToQueue(PINKIE_PIN, glove.pinkie_queue);
    if (retVal != pdPASS) {
      Serial.println("Failed to add to pinkie queue\n");
    }

    retVal = SendToQueue(PALM_PIN, glove.palm_queue);
    if (retVal != pdPASS) {
      Serial.println("Failed to add to palm queue\n");
    }
    
    vTaskDelay(10 / portTICK_PERIOD_MS);  // 10ms freq
  }
}

/**
 * @brief FreeRTOS task that averages queue data for each finger and sends packets over ESP-NOW.
 *
 * The task:
 *  - Reads and averages queued sensor values with ::ReadQueue.
 *  - Packages readings into a @ref packet.
 *  - Prints readings via ::PrintReadings.
 *  - Sends the packet with ::esp_now_send and reports success or failure.
 *
 * @param p_params Pointer to task parameters (unused).
 */
void TransmitTask(void *p_params) {
  packet message;

  while(1) {
    // Take the average for each finger and transmit a packet of averaged readings
    message.thumb_reading = ReadQueue(glove.thumb_queue);
    message.index_reading = ReadQueue(glove.index_queue);
    message.middle_reading = ReadQueue(glove.middle_queue);
    message.ring_reading = ReadQueue(glove.ring_queue);
    message.pinkie_reading = ReadQueue(glove.pinkie_queue);
    message.palm_reading = ReadQueue(glove.palm_queue);

    PrintReadings(&message);

    // Send message over esp_now to receiver
    esp_err_t result = esp_now_send(BROADCAST_ADDRESS, (uint8_t *) &message, sizeof(packet));

    if (result == ESP_OK) {
      Serial.println("Sent with success");
    }
    else {
      Serial.println("Error sending the data");
    }

    vTaskDelay(20 / portTICK_PERIOD_MS);  // freq of 20ms
  }
}

/**
 * @brief Read a single ADC value and send it to a FreeRTOS queue.
 *
 * This function performs an ADC reading on the specified pin (in millivolts)
 * and attempts to enqueue the reading into the provided queue.
 *
 * @param pin   GPIO pin connected to the flex sensor (ADC input).
 * @param queue Handle to the FreeRTOS queue for this sensor.
 *
 * @return pdPASS on success, or an error code from ::xQueueSend on failure.
 */
BaseType_t SendToQueue(const uint32_t pin, QueueHandle_t queue) {
  BaseType_t retVal;
  uint32_t flex_reading;

  flex_reading = analogReadMilliVolts(pin);
  
  retVal = xQueueSend(queue, &flex_reading, 0);
  return retVal;
}

/**
 * @brief Empty a queue and return the average of all readings.
 *
 * This function repeatedly calls ::xQueueReceive with zero block time until
 * the queue is empty. It computes the average of all values removed.
 *
 * @param queue Handle to the FreeRTOS queue containing sensor readings.
 *
 * @return Average of all readings in the queue, or 0 if the queue was empty.
 */
uint16_t ReadQueue(QueueHandle_t queue) {
  uint16_t sum = 0, count = 0;
  uint16_t reading;

  // Read from queue until empty and take average
  while(xQueueReceive(queue, &reading, 0) == pdTRUE) {
    sum += reading;
    count++;
  }

  if (count > 0) {
    return (sum / count);
  } else {
    return 0; // Don't want to divide by zero if nothing in queue
  }  
}

/**
 * @brief Print formatted finger readings to the Serial monitor.
 *
 * @param hand Pointer to a @ref packet structure containing all finger readings.
 */
void PrintReadings(packet *hand) {
  Serial.print("Thumb: ");
  Serial.println(hand->thumb_reading);

  Serial.print("\tIndex: ");
  Serial.println(hand->index_reading);

  Serial.print("\t\t\tMiddle: ");
  Serial.println(hand->middle_reading);

  Serial.print("\t\t\t\tRing: ");
  Serial.println(hand->ring_reading);

  Serial.print("\t\t\t\t\tPinkie: ");
  Serial.println(hand->pinkie_reading);

  Serial.print("\t\t\t\t\t\tPalm: ");
  Serial.println(hand->palm_reading);
}

/**
 * @brief ESP-NOW send callback called after a packet is transmitted.
 *
 * This callback is registered via ::esp_now_register_send_cb and reports
 * whether the last transmission was successful.
 *
 * @param mac_addr MAC address of the peer to which the data was sent.
 * @param status   Transmission status, e.g. ::ESP_NOW_SEND_SUCCESS on success.
 */
void OnDataSent(const uint8_t *mac_addr, esp_now_send_status_t status) {
  Serial.print("\r\nLast Packet Send Status:\t");
  Serial.println(status == ESP_NOW_SEND_SUCCESS ? "Delivery Success" : "Delivery Fail");
}

/**
 * @brief Initialize ESP-NOW communications and register the receiver peer.
 *
 * This function:
 *  - Puts WiFi into station mode.
 *  - Initializes ESP-NOW.
 *  - Registers ::OnDataSent as the send callback.
 *  - Adds the receiver peer specified by ::BROADCAST_ADDRESS.
 *
 * @return true on success, false if initialization or peer registration fails.
 */
bool InitComms() {
  // ESP_NOW Setup
  WiFi.mode(WIFI_MODE_STA);

  // Init ESP-NOW
  if (esp_now_init() != ESP_OK) {
    Serial.println("Error initializing ESP-NOW");
    return false;
  }

  // Once ESPNow is successfully Init, we will register for Send CB to get the status 
  // of Transmitted packet
  esp_now_register_send_cb(OnDataSent);

  // Register peer
  memcpy(peerInfo.peer_addr, BROADCAST_ADDRESS, 6);
  peerInfo.channel = 0;  
  peerInfo.encrypt = false;

    // Add peer        
  if (esp_now_add_peer(&peerInfo) != ESP_OK){
    Serial.println("Failed to add peer");
    return false;
  }

  return true;
}
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

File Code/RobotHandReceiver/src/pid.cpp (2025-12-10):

/**
 * @file pid.cpp
 * @brief PID control and motor control helpers for robotic hand fingers.
 *
 * This module provides:
 *  - Generic PID initialization, reset, and step functions
 *  - Homing control logic for DC motors with encoders
 *  - Position control using PID with PWM + phase output
 *
 * Designed for use with FreeRTOS-based embedded systems.
 */

#include "pid.h"


/**
 * @brief Initialize a PID controller structure.
 *
 * Sets controller gains, output limits, and clears internal state.
 *
 * @param pid      Pointer to PID controller structure.
 * @param kp       Proportional gain.
 * @param ki       Integral gain.
 * @param kd       Derivative gain.
 * @param out_min  Minimum allowable output.
 * @param out_max  Maximum allowable output.
 */
void PID_Init(PID_t *pid, float kp, float ki, float kd, float out_min, float out_max) {
  pid->kp = kp;
  pid->ki = ki;
  pid->kd = kd;
  pid->integral = 0.0f;
  pid->prev_error = 0.0f;
  pid->out_min = out_min;
  pid->out_max = out_max;
  return;
}

/**
 * @brief Initialize all PID controllers used by the robotic hand.
 *
 * Sets gains and output limits for all fingers and palm.
 */
void InitPIDs() {
  // output range: -1023..1023 for 10-bit PWM
  PID_Init(&pid_thumb,  2.0f, 0.2f, 0.5f, -1023.0f, 1023.0f);
  PID_Init(&pid_index,  2.0f, 0.2f, 0.5f, -1023.0f, 1023.0f);
  PID_Init(&pid_middle,  2.0f, 0.2f, 0.5f, -1023.0f, 1023.0f);
  PID_Init(&pid_ring,  2.0f, 0.2f, 0.5f, -1023.0f, 1023.0f);
  PID_Init(&pid_pinkie,  2.0f, 0.2f, 0.5f, -1023.0f, 1023.0f);
  PID_Init(&pid_palm,  2.0f, 0.2f, 0.5f, -1023.0f, 1023.0f);
  return;
}

/**
 * @brief Reset a PID controller's internal state.
 *
 * Clears the integral accumulator and previous error term.
 *
 * @param pid Pointer to PID controller structure.
 */
void PID_Reset(PID_t *pid) {
  // Reset integral and prev terms of pid
  pid->integral = 0.0f;
  pid->prev_error = 0.0f;
  return;
}

/**
 * @brief Perform one PID control step.
 *
 * Computes the control output using proportional, integral,
 * and derivative terms and applies output clamping.
 *
 * @param pid    Pointer to PID controller structure.
 * @param error  Current control error (setpoint - measurement).
 * @param dt     Time step in seconds since last update.
 *
 * @return Saturated control output value.
 */
float PID_Step(PID_t *pid, float error, float dt) {
  pid->integral += error * dt;

  float derivative = (error - pid->prev_error) / dt;
  float out = pid->kp * error + pid->ki * pid->integral + pid->kd * derivative;

  if (out > pid->out_max) out = pid->out_max;
  if (out < pid->out_min) out = pid->out_min;

  pid->prev_error = error;
  return out;
}

/**
 * @brief Set motor direction based on signed control effort.
 *
 * Uses the sign of the control signal to determine the motor
 * rotation direction via the phase pin.
 *
 * @param u               Signed control output.
 * @param motor_phase_pin GPIO pin controlling motor direction.
 */
void SetPhase(float u, uint32_t motor_phase_pin) {
  // Find which direction the motor should be moved to get to desired encoder value
  // Set phase pin to match calculated direction
  digitalWrite(motor_phase_pin,(u >= 0.0f) ? HIGH : LOW);
}

/**
 * @brief Perform PID-based position control for a single finger motor.
 *
 * Computes the control effort using PID, sets motor direction,
 * enforces a minimum PWM threshold, and applies the PWM output.
 *
 * @param enc          Current encoder reading.
 * @param target       Desired encoder target value.
 * @param pid          Pointer to PID controller for this finger.
 * @param pwm_channel  LEDC PWM channel controlling the motor.
 * @param phase_pin    GPIO pin controlling motor direction.
 * @param dt           Control loop timestep in seconds.
 */
void PositionControlFinger(uint32_t enc, uint32_t target,
                           PID_t *pid, int pwm_channel, int phase_pin,
                           float dt)
{
  float error = (float)target - (float)enc;
  float u = PID_Step(pid, error, dt);  // signed

  SetPhase(u, phase_pin); // Find direction to move in

  float mag = fabsf(u);
  int pwm = (int)mag;

  // Add a minimum like homing
  const int POS_PWM_MIN = 300;   // tune this
  const int POS_PWM_MAX = 1023; // full scale

  if (pwm > POS_PWM_MAX) pwm = POS_PWM_MAX;
  if (pwm > 0 && pwm < POS_PWM_MIN) pwm = POS_PWM_MIN;  // prevent dead zone

  ledcWrite(pwm_channel, pwm);
  return;
}


/**
 * @brief Home a single finger motor to a reference position.
 *
 * Drives the motor toward a known home encoder value using
 * a proportional controller until the error falls below
 * ::HOMING_THRESHOLD.
 *
 * @param enc          Current encoder reading.
 * @param home_target  Desired home encoder value.
 * @param pwm_channel  LEDC PWM channel controlling the motor.
 * @param phase_pin    GPIO pin controlling motor direction.
 *
 * @return true if the finger is homed, false otherwise.
 */
bool HomeFinger(uint32_t enc, uint32_t home_target,
                int pwm_channel, int phase_pin)
{
  int32_t err = (int32_t)home_target - (int32_t)enc;
  int32_t mag = abs(err);

  if (mag <= HOMING_THRESHOLD) {
    ledcWrite(pwm_channel, 0);  // Close enough stop this motor
    return true;
  }

  float u = HOMING_KP * (float)err;
  SetPhase(u, phase_pin);

  float mag_u = fabsf(u);
  int pwm = (int)mag_u; // Get magnitude for duty cycle

  // Clamp output
  if (pwm > HOMING_PWM_MAX) pwm = HOMING_PWM_MAX;
  if (pwm < HOMING_PWM_MIN) pwm = HOMING_PWM_MIN;

  ledcWrite(pwm_channel, pwm);
  return false;
}

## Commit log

2025-10-17 First Revision of PCB Design
    [RobotHand.kicad_sch]
2025-10-17 Added footprints to first PCB version
    [RobotHand.kicad_sch]
2025-11-11 Version 2 of PCB
    [RobotHand.kicad_pcb, RobotHand.kicad_sch]
2025-12-03 Code with all fingers commented out
2025-12-03 Single finger homing working not normal operation
2025-12-04 One finger working
2025-12-04 Functionality for all fingers done
2025-12-10 STEP file of PCB
    [RobotHandFINAL.step]
2025-12-10 Fixing READMEs
    [RobotHand_V2.kicad_sch]
2025-12-10 Finished receiver readme
    [RobotHand_V2.kicad_sch]
2025-12-10 Added link to CAD README
